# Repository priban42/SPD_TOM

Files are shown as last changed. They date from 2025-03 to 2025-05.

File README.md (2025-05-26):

# Toilet Occupancy Monitor

This project implements a system for monitoring the occupancy of toilet stalls and recording sanitation events within a faculty building.

## Features

- Detects stall occupancy using a combination of Hall sensors (door open/close) and PIR motion sensors.
- Records sanitation events using RFID tags.
- Sends collected data via WiFi to a web server.
- Web server stores data in SQLite and provides visualization of occupancy and sanitation history.
- User-friendly web interface with floor plans and detailed stall status.

## Hardware

- ESP32 microcontroller for control and WiFi communication.
- PN532 RFID reader module.
- Hall sensor (OH137) and PIR sensor (SR602) for presence detection.
- Li-ion battery (18650) with power management modules.

## Software

- Device firmware programmed for sensor reading, event detection, and JSON data transmission.
- Web server implemented in Python using Flask framework.
- Data visualization based on SVG floor plans.

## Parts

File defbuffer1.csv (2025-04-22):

Style | Standard
Append Mode | 1
Fill Mode | 1
Capacity | 100000
Count | 21027
Base Time Seconds | 1744929068
Base Time Fractional | .628364260
Index | Reading | Unit | Range Digits | Disp Digits | Math | Start Group | Limit1 High | Limit1 Low | Limit2 High | Limit2 Low | Terminal | Questionable | Origin | Value | Unit | Digits | Output | Sense | Source Limit | Overtemp | Date | Time | Fractional Seconds
1 | 1.899451490317e-05 | Amp DC | 1 | 6.5 | F | F | F | F | F | F | Front | F | Main | 0.0001027817780 | Volt DC | 1 | F | 2W | F | F | 04/17/2025 | 22:31:08 | .628364260
2 | 7.437442036462e-06 | Amp DC | 1 | 6.5 | F | F | F | F | F | F | Front | F | Main | -0.0001242152648 | Volt DC | 1 | F | 2W | F | F | 04/17/2025 | 22:31:08 | .631889340
3 | 1.899451490317e-05 | Amp DC | 1 | 6.5 | F | F | F | F | F | F | Front | F | Main | 0.0001027817780 | Volt DC | 1 | F | 2W | F | F | 04/17/2025 | 22:31:08 | .635377580
4 | 1.899413655337e-05 | Amp DC | 1 | 6.5 | F | F | F | F | F | F | Front | F | Main | -0.0000107176747 | Volt DC | 1 | F | 2W | F | F | 04/17/2025 | 22:31:08 | .638861860
5 | 1.899451490317e-05 | Amp DC | 1 | 6.5 | F | F | F | F | F | F | Front | F | Main | -0.0000107185988 | Volt DC | 1 | F | 2W | F | F | 04/17/2025 | 22:31:08 | .642365300
6 | 1.899413655337e-05 | Amp DC | 1 | 6.5 | F | F | F | F | F | F | Front | F | Main | 0.0001027817780 | Volt DC | 1 | F | 2W | F | F | 04/17/2025 | 22:31:08 | .645855260
7 | 1.899451490317e-05 | Amp DC | 1 | 6.5 | F | F | F | F | F | F | Front | F | Main | 0.0001027817780 | Volt DC | 1 | F | 2W | F | F | 04/17/2025 | 22:31:08 | .649350460
8 | 1.899451490317e-05 | Amp DC | 1 | 6.5 | F | F | F | F | F | F | Front | F | Main | -0.0000107185988 | Volt DC | 1 | F | 2W | F | F | 04/17/2025 | 22:31:08 | .652854140
9 | 7.43772216083e-06 | Amp DC | 1 | 6.5 | F | F | F | F | F | F | Front | F | Main | 0.0001027817780 | Volt DC | 1 | F | 2W | F | F | 04/17/2025 | 22:31:08 | .656342200
10 | 1.899413655337e-05 | Amp DC | 1 | 6.5 | F | F | F | F | F | F | Front | F | Main | -0.0000107176747 | Volt DC | 1 | F | 2W | F | F | 04/17/2025 | 22:31:08 | .659834880
11 | 3.055101115024e-05 | Amp DC | 1 | 6.5 | F | F | F | F | F | F | Front | F | Main | -0.0000107185988 | Volt DC | 1 | F | 2W | F | F | 04/17/2025 | 22:31:08 | .663328260
12 | 3.055101115024e-05 | Amp DC | 1 | 6.5 | F | F | F | F | F | F | Front | F | Main | 0.0001027817780 | Volt DC | 1 | F | 2W | F | F | 04/17/2025 | 22:31:08 | .666814880
13 | 1.899451490317e-05 | Amp DC | 1 | 6.5 | F | F | F | F | F | F | Front | F | Main | -0.0000107185988 | Volt DC | 1 | F | 2W | F | F | 04/17/2025 | 22:31:08 | .670305920
14 | 1.899451490317e-05 | Amp DC | 1 | 6.5 | F | F | F | F | F | F | Front | F | Main | -0.0000107185988 | Volt DC | 1 | F | 2W | F | F | 04/17/2025 | 22:31:08 | .673803360
15 | 1.899413655337e-05 | Amp DC | 1 | 6.5 | F | F | F | F | F | F | Front | F | Main | -0.0000107176747 | Volt DC | 1 | F | 2W | F | F | 04/17/2025 | 22:31:08 | .677299720
16 | 1.899488597701e-05 | Amp DC | 1 | 6.5 | F | F | F | F | F | F | Front | F | Main | -0.0000107195156 | Volt DC | 1 | F | 2W | F | F | 04/17/2025 | 22:31:08 | .680796760
17 | 1.899413655337e-05 | Amp DC | 1 | 6.5 | F | F | F | F | F | F | Front | F | Main | 0.0001027817780 | Volt DC | 1 | F | 2W | F | F | 04/17/2025 | 22:31:08 | .684284560
18 | 1.899451490317e-05 | Amp DC | 1 | 6.5 | F | F | F | F | F | F | Front | F | Main | -0.0001242189755 | Volt DC | 1 | F | 2W | F | F | 04/17/2025 | 22:31:08 | .687781080
19 | 1.899451490317e-05 | Amp DC | 1 | 6.5 | F | F | F | F | F | F | Front | F | Main | -0.0000107185988 | Volt DC | 1 | F | 2W | F | F | 04/17/2025 | 22:31:08 | .691278700
20 | 1.899451490317e-05 | Amp DC | 1 | 6.5 | F | F | F | F | F | F | Front | F | Main | -0.0000107185988 | Volt DC | 1 | F | 2W | F | F | 04/17/2025 | 22:31:08 | .694774800
21 | 1.899413655337e-05 | Amp DC | 1 | 6.5 | F | F | F | F | F | F | Front | F | Main | -0.0000107176747 | Volt DC | 1 | F | 2W | F | F | 04/17/2025 | 22:31:08 | .698256940
22 | 7.438005923177e-06 | Amp DC | 1 | 6.5 | F | F | F | F | F | F | Front | F | Main | 0.0001027817780 | Volt DC | 1 | F | 2W | F | F | 04/17/2025 | 22:31:08 | .701757300
23 | 3.055148408748e-05 | Amp DC | 1 | 6.5 | F | F | F | F | F | F | Front | F | Main | 0.0001027817780 | Volt DC | 1 | F | 2W | F | F | 04/17/2025 | 22:31:08 | .705240080
24 | -4.118686774746e-06 | Amp DC | 1 | 6.5 | F | F | F | F | F | F | Front | F | Main | -0.0001242171274 | Volt DC | 1 | F | 2W | F | F | 04/17/2025 | 22:31:08 | .708733920
25 | 1.899451490317e-05 | Amp DC | 1 | 6.5 | F | F | F | F | F | F | Front | F | Main | 0.0001027817780 | Volt DC | 1 | F | 2W | F | F | 04/17/2025 | 22:31:08 | .712229020
26 | 3.055148408748e-05 | Amp DC | 1 | 6.5 | F | F | F | F | F | F | Front | F | Main | 0.0001027817780 | Volt DC | 1 | F | 2W | F | F | 04/17/2025 | 22:31:08 | .715723320
27 | 1.899413655337e-05 | Amp DC | 1 | 6.5 | F | F | F | F | F | F | Front | F | Main | -0.0000107176747 | Volt DC | 1 | F | 2W | F | F | 04/17/2025 | 22:31:08 | .719209900
28 | 7.437442036462e-06 | Amp DC | 1 | 6.5 | F | F | F | F | F | F | Front | F | Main | -0.0001242152648 | Volt DC | 1 | F | 2W | F | F | 04/17/2025 | 22:31:08 | .722717500
29 | 1.899451490317e-05 | Amp DC | 1 | 6.5 | F | F | F | F | F | F | Front | F | Main | -0.0001242189755 | Volt DC | 1 | F | 2W | F | F | 04/17/2025 | 22:31:08 | .726208460
30 | 1.899488597701e-05 | Amp DC | 1 | 6.5 | F | F | F | F | F | F | Front | F | Main | -0.0000107195156 | Volt DC | 1 | F | 2W | F | F | 04/17/2025 | 22:31:08 | .729710020
31 | 1.899451490317e-05 | Amp DC | 1 | 6.5 | F | F | F | F | F | F | Front | F | Main | 0.0001027817780 | Volt DC | 1 | F | 2W | F | F | 04/17/2025 | 22:31:08 | .733204280
32 | 1.899451490317e-05 | Amp DC | 1 | 6.5 | F | F | F | F | F | F | Front | F | Main | 0.0001027817780 | Volt DC | 1 | F | 2W | F | F | 04/17/2025 | 22:31:08 | .736700640
33 | 4.210752376821e-05 | Amp DC | 1 | 6.5 | F | F | F | F | F | F | Front | F | Main | 0.0001027817780 | Volt DC | 1 | F | 2W | F | F | 04/17/2025 | 22:31:08 | .740196240
34 | 7.43772216083e-06 | Amp DC | 1 | 6.5 | F | F | F | F | F | F | Front | F | Main | -0.0001242171274 | Volt DC | 1 | F | 2W | F | F | 04/17/2025 | 22:31:08 | .743700200
35 | 7.43772216083e-06 | Amp DC | 1 | 6.5 | F | F | F | F | F | F | Front | F | Main | -0.0000107176747 | Volt DC | 1 | F | 2W | F | F | 04/17/2025 | 22:31:08 | .747187960
36 | 1.899413655337e-05 | Amp DC | 1 | 6.5 | F | F | F | F | F | F | Front | F | Main | -0.0000107176747 | Volt DC | 1 | F | 2W | F | F | 04/17/2025 | 22:31:08 | .750697300
37 | 1.899451490317e-05 | Amp DC | 1 | 6.5 | F | F | F | F | F | F | Front | F | Main | -0.0000107185988 | Volt DC | 1 | F | 2W | F | F | 04/17/2025 | 22:31:08 | .754184920
38 | 1.899413655337e-05 | Amp DC | 1 | 6.5 | F | F | F | F | F | F | Front | F | Main | -0.0000107176747 | Volt DC | 1 | F | 2W | F | F | 04/17/2025 | 22:31:08 | .757678960
39 | 1.899413655337e-05 | Amp DC | 1 | 6.5 | F | F | F | F | F | F | Front | F | Main | 0.0001027817780 | Volt DC | 1 | F | 2W | F | F | 04/17/2025 | 22:31:08 | .761170800
40 | 3.055148408748e-05 | Amp DC | 1 | 6.5 | F | F | F | F | F | F | Front | F | Main | 0.0001027817780 | Volt DC | 1 | F | 2W | F | F | 04/17/2025 | 22:31:08 | .764665780
41 | 1.899413655337e-05 | Amp DC | 1 | 6.5 | F | F | F | F | F | F | Front | F | Main | 0.0001027817780 | Volt DC | 1 | F | 2W | F | F | 04/17/2025 | 22:31:08 | .768152760
42 | 7.43772216083e-06 | Amp DC | 1 | 6.5 | F | F | F | F | F | F | Front | F | Main | -0.0002377165656 | Volt DC | 1 | F | 2W | F | F | 04/17/2025 | 22:31:08 | .771647500
43 | 1.899451490317e-05 | Amp DC | 1 | 6.5 | F | F | F | F | F | F | Front | F | Main | -0.0000107185988 | Volt DC | 1 | F | 2W | F | F | 04/17/2025 | 22:31:08 | .775144360
44 | 1.899413655337e-05 | Amp DC | 1 | 6.5 | F | F | F | F | F | F | Front | F | Main | -0.0000107176747 | Volt DC | 1 | F | 2W | F | F | 04/17/2025 | 22:31:08 | .778635900
45 | 3.055148408748e-05 | Amp DC | 1 | 6.5 | F | F | F | F | F | F | Front | F | Main | -0.0000107195156 | Volt DC | 1 | F | 2W | F | F | 04/17/2025 | 22:31:08 | .782137940
46 | 1.899451490317e-05 | Amp DC | 1 | 6.5 | F | F | F | F | F | F | Front | F | Main | -0.0000107185988 | Volt DC | 1 | F | 2W | F | F | 04/17/2025 | 22:31:08 | .785626280
47 | 7.438005923177e-06 | Amp DC | 1 | 6.5 | F | F | F | F | F | F | Front | F | Main | -0.0000107185988 | Volt DC | 1 | F | 2W | F | F | 04/17/2025 | 22:31:08 | .789108080
48 | 1.899413655337e-05 | Amp DC | 1 | 6.5 | F | F | F | F | F | F | Front | F | Main | 0.0001027817780 | Volt DC | 1 | F | 2W | F | F | 04/17/2025 | 22:31:08 | .792606520
49 | -4.118686774746e-06 | Amp DC | 1 | 6.5 | F | F | F | F | F | F | Front | F | Main | -0.0001242171274 | Volt DC | 1 | F | 2W | F | F | 04/17/2025 | 22:31:08 | .796088800
50 | 7.43772216083e-06 | Amp DC | 1 | 6.5 | F | F | F | F | F | F | Front | F | Main | -0.0001242171274 | Volt DC | 1 | F | 2W | F | F | 04/17/2025 | 22:31:08 | .799568960
51 | 1.899413655337e-05 | Amp DC | 1 | 6.5 | F | F | F | F | F | F | Front | F | Main | -0.0000107176747 | Volt DC | 1 | F | 2W | F | F | 04/17/2025 | 22:31:08 | .803068880
52 | 7.438005923177e-06 | Amp DC | 1 | 6.5 | F | F | F | F | F | F | Front | F | Main | 0.0001027817780 | Volt DC | 1 | F | 2W | F | F | 04/17/2025 | 22:31:08 | .806552980
53 | 1.899451490317e-05 | Amp DC | 1 | 6.5 | F | F | F | F | F | F | Front | F | Main | -0.0000107185988 | Volt DC | 1 | F | 2W | F | F | 04/17/2025 | 22:31:08 | .810052540
54 | 1.899413655337e-05 | Amp DC | 1 | 6.5 | F | F | F | F | F | F | Front | F | Main | -0.0001242171274 | Volt DC | 1 | F | 2W | F | F | 04/17/2025 | 22:31:08 | .813544060
55 | 7.437442036462e-06 | Amp DC | 1 | 6.5 | F | F | F | F | F | F | Front | F | Main | -0.0000107167434 | Volt DC | 1 | F | 2W | F | F | 04/17/2025 | 22:31:08 | .817030040
56 | 1.899451490317e-05 | Amp DC | 1 | 6.5 | F | F | F | F | F | F | Front | F | Main | -0.0000107185988 | Volt DC | 1 | F | 2W | F | F | 04/17/2025 | 22:31:08 | .820521600
57 | -4.118686774746e-06 | Amp DC | 1 | 6.5 | F | F | F | F | F | F | Front | F | Main | -0.0001242171274 | Volt DC | 1 | F | 2W | F | F | 04/17/2025 | 22:31:08 | .824012100
58 | 1.899451490317e-05 | Amp DC | 1 | 6.5 | F | F | F | F | F | F | Front | F | Main | -0.0000107185988 | Volt DC | 1 | F | 2W | F | F | 04/17/2025 | 22:31:08 | .827494740
59 | 3.055054548895e-05 | Amp DC | 1 | 6.5 | F | F | F | F | F | F | Front | F | Main | 0.0001027817780 | Volt DC | 1 | F | 2W | F | F | 04/17/2025 | 22:31:08 | .830990060
60 | 7.43772216083e-06 | Amp DC | 1 | 6.5 | F | F | F | F | F | F | Front | F | Main | -0.0000107176747 | Volt DC | 1 | F | 2W | F | F | 04/17/2025 | 22:31:08 | .834472160
61 | 7.438005923177e-06 | Amp DC | 1 | 6.5 | F | F | F | F | F | F | Front | F | Main | -0.0000107185988 | Volt DC | 1 | F | 2W | F | F | 04/17/2025 | 22:31:08 | .837957860
62 | 7.438005923177e-06 | Amp DC | 1 | 6.5 | F | F | F | F | F | F | Front | F | Main | -0.0000107185988 | Volt DC | 1 | F | 2W | F | F | 04/17/2025 | 22:31:08 | .841454880
63 | 1.899451490317e-05 | Amp DC | 1 | 6.5 | F | F | F | F | F | F | Front | F | Main | -0.0000107185988 | Volt DC | 1 | F | 2W | F | F | 04/17/2025 | 22:31:08 | .844939920
64 | 3.055054548895e-05 | Amp DC | 1 | 6.5 | F | F | F | F | F | F | Front | F | Main | 0.0001027817780 | Volt DC | 1 | F | 2W | F | F | 04/17/2025 | 22:31:08 | .848427260
65 | 3.055148408748e-05 | Amp DC | 1 | 6.5 | F | F | F | F | F | F | Front | F | Main | 0.0001027817780 | Volt DC | 1 | F | 2W | F | F | 04/17/2025 | 22:31:08 | .851927080
66 | -4.118875949644e-06 | Amp DC | 1 | 6.5 | F | F | F | F | F | F | Front | F | Main | -0.0000107167434 | Volt DC | 1 | F | 2W | F | F | 04/17/2025 | 22:31:08 | .855410580
67 | 7.437442036462e-06 | Amp DC | 1 | 6.5 | F | F | F | F | F | F | Front | F | Main | -0.0000107167434 | Volt DC | 1 | F | 2W | F | F | 04/17/2025 | 22:31:08 | .858895800
68 | 1.899413655337e-05 | Amp DC | 1 | 6.5 | F | F | F | F | F | F | Front | F | Main | -0.0000107176747 | Volt DC | 1 | F | 2W | F | F | 04/17/2025 | 22:31:08 | .862388300
69 | 7.438005923177e-06 | Amp DC | 1 | 6.5 | F | F | F | F | F | F | Front | F | Main | 0.0001027817780 | Volt DC | 1 | F | 2W | F | F | 04/17/2025 | 22:31:08 | .865876520
70 | 3.055148408748e-05 | Amp DC | 1 | 6.5 | F | F | F | F | F | F | Front | F | Main | 0.0001027817780 | Volt DC | 1 | F | 2W | F | F | 04/17/2025 | 22:31:08 | .869357180
71 | 3.055148408748e-05 | Amp DC | 1 | 6.5 | F | F | F | F | F | F | Front | F | Main | 0.0001027817780 | Volt DC | 1 | F | 2W | F | F | 04/17/2025 | 22:31:08 | .872854620
72 | 3.055148408748e-05 | Amp DC | 1 | 6.5 | F | F | F | F | F | F | Front | F | Main | -0.0000107195156 | Volt DC | 1 | F | 2W | F | F | 04/17/2025 | 22:31:08 | .876340400
73 | 1.899451490317e-05 | Amp DC | 1 | 6.5 | F | F | F | F | F | F | Front | F | Main | -0.0000107185988 | Volt DC | 1 | F | 2W | F | F | 04/17/2025 | 22:31:08 | .879821200
74 | 1.899451490317e-05 | Amp DC | 1 | 6.5 | F | F | F | F | F | F | Front | F | Main | 0.0001027817780 | Volt DC | 1 | F | 2W | F | F | 04/17/2025 | 22:31:08 | .883312820
75 | 1.899451490317e-05 | Amp DC | 1 | 6.5 | F | F | F | F | F | F | Front | F | Main | -0.0001242189755 | Volt DC | 1 | F | 2W | F | F | 04/17/2025 | 22:31:08 | .886805340
76 | 1.899413655337e-05 | Amp DC | 1 | 6.5 | F | F | F | F | F | F | Front | F | Main | -0.0000107176747 | Volt DC | 1 | F | 2W | F | F | 04/17/2025 | 22:31:08 | .890308120
77 | 3.055148408748e-05 | Amp DC | 1 | 6.5 | F | F | F | F | F | F | Front | F | Main | 0.0001027817780 | Volt DC | 1 | F | 2W | F | F | 04/17/2025 | 22:31:08 | .893807720
78 | 7.438005923177e-06 | Amp DC | 1 | 6.5 | F | F | F | F | F | F | Front | F | Main | -0.0000107185988 | Volt DC | 1 | F | 2W | F | F | 04/17/2025 | 22:31:08 | .897288800
79 | 1.899451490317e-05 | Amp DC | 1 | 6.5 | F | F | F | F | F | F | Front | F | Main | -0.0001242189755 | Volt DC | 1 | F | 2W | F | F | 04/17/2025 | 22:31:08 | .900787480
80 | 1.899413655337e-05 | Amp DC | 1 | 6.5 | F | F | F | F | F | F | Front | F | Main | -0.0000107176747 | Volt DC | 1 | F | 2W | F | F | 04/17/2025 | 22:31:08 | .904274160
81 | 3.055148408748e-05 | Amp DC | 1 | 6.5 | F | F | F | F | F | F | Front | F | Main | -0.0000107195156 | Volt DC | 1 | F | 2W | F | F | 04/17/2025 | 22:31:08 | .907771860
82 | 1.899413655337e-05 | Amp DC | 1 | 6.5 | F | F | F | F | F | F | Front | F | Main | -0.0000107176747 | Volt DC | 1 | F | 2W | F | F | 04/17/2025 | 22:31:08 | .911266000
83 | 3.055148408748e-05 | Amp DC | 1 | 6.5 | F | F | F | F | F | F | Front | F | Main | 0.0001027817780 | Volt DC | 1 | F | 2W | F | F | 04/17/2025 | 22:31:08 | .914755960
84 | 1.899413655337e-05 | Amp DC | 1 | 6.5 | F | F | F | F | F | F | Front | F | Main | -0.0001242171274 | Volt DC | 1 | F | 2W | F | F | 04/17/2025 | 22:31:08 | .918236720
85 | 1.899413655337e-05 | Amp DC | 1 | 6.5 | F | F | F | F | F | F | Front | F | Main | -0.0000107176747 | Volt DC | 1 | F | 2W | F | F | 04/17/2025 | 22:31:08 | .921736860
86 | 7.438005923177e-06 | Amp DC | 1 | 6.5 | F | F | F | F | F | F | Front | F | Main | -0.0000107185988 | Volt DC | 1 | F | 2W | F | F | 04/17/2025 | 22:31:08 | .925220400
87 | 1.899451490317e-05 | Amp DC | 1 | 6.5 | F | F | F | F | F | F | Front | F | Main | -0.0000107185988 | Volt DC | 1 | F | 2W | F | F | 04/17/2025 | 22:31:08 | .928716080
88 | 3.055101115024e-05 | Amp DC | 1 | 6.5 | F | F | F | F | F | F | Front | F | Main | 0.0001027817780 | Volt DC | 1 | F | 2W | F | F | 04/17/2025 | 22:31:08 | .932222320
89 | 1.899451490317e-05 | Amp DC | 1 | 6.5 | F | F | F | F | F | F | Front | F | Main | -0.0000107185988 | Volt DC | 1 | F | 2W | F | F | 04/17/2025 | 22:31:08 | .935718900
90 | 3.055101115024e-05 | Amp DC | 1 | 6.5 | F | F | F | F | F | F | Front | F | Main | 0.0001027817780 | Volt DC | 1 | F | 2W | F | F | 04/17/2025 | 22:31:08 | .939203220
91 | 7.438005923177e-06 | Amp DC | 1 | 6.5 | F | F | F | F | F | F | Front | F | Main | -0.0000107185988 | Volt DC | 1 | F | 2W | F | F | 04/17/2025 | 22:31:08 | .942714820
92 | 7.43772216083e-06 | Amp DC | 1 | 6.5 | F | F | F | F | F | F | Front | F | Main | -0.0000107176747 | Volt DC | 1 | F | 2W | F | F | 04/17/2025 | 22:31:08 | .946199000
93 | 1.899451490317e-05 | Amp DC | 1 | 6.5 | F | F | F | F | F | F | Front | F | Main | -0.0000107185988 | Volt DC | 1 | F | 2W | F | F | 04/17/2025 | 22:31:08 | .949700220
94 | 7.437442036462e-06 | Amp DC | 1 | 6.5 | F | F | F | F | F | F | Front | F | Main | -0.0001242152648 | Volt DC | 1 | F | 2W | F | F | 04/17/2025 | 22:31:08 | .953199160
95 | 1.899413655337e-05 | Amp DC | 1 | 6.5 | F | F | F | F | F | F | Front | F | Main | -0.0000107176747 | Volt DC | 1 | F | 2W | F | F | 04/17/2025 | 22:31:08 | .956693460
96 | 3.055148408748e-05 | Amp DC | 1 | 6.5 | F | F | F | F | F | F | Front | F | Main | 0.0001027817780 | Volt DC | 1 | F | 2W | F | F | 04/17/2025 | 22:31:08 | .960189220
97 | 7.43772216083e-06 | Amp DC | 1 | 6.5 | F | F | F | F | F | F | Front | F | Main | -0.0001242171274 | Volt DC | 1 | F | 2W | F | F | 04/17/2025 | 22:31:08 | .963691920
98 | 3.055101115024e-05 | Amp DC | 1 | 6.5 | F | F | F | F | F | F | Front | F | Main | 0.0001027817780 | Volt DC | 1 | F | 2W | F | F | 04/17/2025 | 22:31:08 | .967175260
99 | 1.899413655337e-05 | Amp DC | 1 | 6.5 | F | F | F | F | F | F | Front | F | Main | -0.0000107176747 | Volt DC | 1 | F | 2W | F | F | 04/17/2025 | 22:31:08 | .970681300
100 | 1.899451490317e-05 | Amp DC | 1 | 6.5 | F | F | F | F | F | F | Front | F | Main | -0.0000107185988 | Volt DC | 1 | F | 2W | F | F | 04/17/2025 | 22:31:08 | .974171060
101 | 1.899451490317e-05 | Amp DC | 1 | 6.5 | F | F | F | F | F | F | Front | F | Main | -0.0000107185988 | Volt DC | 1 | F | 2W | F | F | 04/17/2025 | 22:31:08 | .977652120
102 | 1.899451490317e-05 | Amp DC | 1 | 6.5 | F | F | F | F | F | F | Front | F | Main | -0.0000107185988 | Volt DC | 1 | F | 2W | F | F | 04/17/2025 | 22:31:08 | .981148680
103 | 1.899451490317e-05 | Amp DC | 1 | 6.5 | F | F | F | F | F | F | Front | F | Main | -0.0000107185988 | Volt DC | 1 | F | 2W | F | F | 04/17/2025 | 22:31:08 | .984631300
104 | 4.210808401695e-05 | Amp DC | 1 | 6.5 | F | F | F | F | F | F | Front | F | Main | 0.0001027817780 | Volt DC | 1 | F | 2W | F | F | 04/17/2025 | 22:31:08 | .988112420
105 | 3.055148408748e-05 | Amp DC | 1 | 6.5 | F | F | F | F | F | F | Front | F | Main | 0.0001027817780 | Volt DC | 1 | F | 2W | F | F | 04/17/2025 | 22:31:08 | .991609840
106 | 3.055148408748e-05 | Amp DC | 1 | 6.5 | F | F | F | F | F | F | Front | F | Main | 0.0001027817780 | Volt DC | 1 | F | 2W | F | F | 04/17/2025 | 22:31:08 | .995092440
107 | 1.899413655337e-05 | Amp DC | 1 | 6.5 | F | F | F | F | F | F | Front | F | Main | -0.0000107176747 | Volt DC | 1 | F | 2W | F | F | 04/17/2025 | 22:31:08 | .998574180
108 | 1.899451490317e-05 | Amp DC | 1 | 6.5 | F | F | F | F | F | F | Front | F | Main | -0.0000107185988 | Volt DC | 1 | F | 2W | F | F | 04/17/2025 | 22:31:09 | .002066860
109 | 1.899451490317e-05 | Amp DC | 1 | 6.5 | F | F | F | F | F | F | Front | F | Main | -0.0000107185988 | Volt DC | 1 | F | 2W | F | F | 04/17/2025 | 22:31:09 | .005548520
110 | 1.899451490317e-05 | Amp DC | 1 | 6.5 | F | F | F | F | F | F | Front | F | Main | -0.0000107185988 | Volt DC | 1 | F | 2W | F | F | 04/17/2025 | 22:31:09 | .009035060
111 | 1.899451490317e-05 | Amp DC | 1 | 6.5 | F | F | F | F | F | F | Front | F | Main | -0.0000107185988 | Volt DC | 1 | F | 2W | F | F | 04/17/2025 | 22:31:09 | .012526860
112 | 1.899451490317e-05 | Amp DC | 1 | 6.5 | F | F | F | F | F | F | Front | F | Main | -0.0000107185988 | Volt DC | 1 | F | 2W | F | F | 04/17/2025 | 22:31:09 | .016011800
113 | 1.899451490317e-05 | Amp DC | 1 | 6.5 | F | F | F | F | F | F | Front | F | Main | -0.0000107185988 | Volt DC | 1 | F | 2W | F | F | 04/17/2025 | 22:31:09 | .019497280
114 | 7.43772216083e-06 | Amp DC | 1 | 6.5 | F | F | F | F | F | F | Front | F | Main | -0.0000107176747 | Volt DC | 1 | F | 2W | F | F | 04/17/2025 | 22:31:09 | .022989840
115 | 1.899413655337e-05 | Amp DC | 1 | 6.5 | F | F | F | F | F | F | Front | F | Main | 0.0001027817780 | Volt DC | 1 | F | 2W | F | F | 04/17/2025 | 22:31:09 | .026534820
116 | 7.437442036462e-06 | Amp DC | 1 | 6.5 | F | F | F | F | F | F | Front | F | Main | -0.0001242152648 | Volt DC | 1 | F | 2W | F | F | 04/17/2025 | 22:31:09 | .030054120
117 | 1.899413655337e-05 | Amp DC | 1 | 6.5 | F | F | F | F | F | F | Front | F | Main | -0.0000107176747 | Volt DC | 1 | F | 2W | F | F | 04/17/2025 | 22:31:09 | .033545000
118 | 7.43772216083e-06 | Amp DC | 1 | 6.5 | F | F | F | F | F | F | Front | F | Main | 0.0001027817780 | Volt DC | 1 | F | 2W | F | F | 04/17/2025 | 22:31:09 | .037033960
119 | 1.899413655337e-05 | Amp DC | 1 | 6.5 | F | F | F | F | F | F | Front | F | Main | -0.0000107176747 | Volt DC | 1 | F | 2W | F | F | 04/17/2025 | 22:31:09 | .040530060
120 | 1.899413655337e-05 | Amp DC | 1 | 6.5 | F | F | F | F | F | F | Front | F | Main | -0.0000107176747 | Volt DC | 1 | F | 2W | F | F | 04/17/2025 | 22:31:09 | .044015020
121 | 7.438005923177e-06 | Amp DC | 1 | 6.5 | F | F | F | F | F | F | Front | F | Main | -0.0000107185988 | Volt DC | 1 | F | 2W | F | F | 04/17/2025 | 22:31:09 | .047497380
122 | 3.055148408748e-05 | Amp DC | 1 | 6.5 | F | F | F | F | F | F | Front | F | Main | 0.0001027817780 | Volt DC | 1 | F | 2W | F | F | 04/17/2025 | 22:31:09 | .051001820
123 | 1.899413655337e-05 | Amp DC | 1 | 6.5 | F | F | F | F | F | F | Front | F | Main | -0.0000107176747 | Volt DC | 1 | F | 2W | F | F | 04/17/2025 | 22:31:09 | .054491780
124 | 7.43772216083e-06 | Amp DC | 1 | 6.5 | F | F | F | F | F | F | Front | F | Main | -0.0000107176747 | Volt DC | 1 | F | 2W | F | F | 04/17/2025 | 22:31:09 | .057981040
125 | 1.899413655337e-05 | Amp DC | 1 | 6.5 | F | F | F | F | F | F | Front | F | Main | -0.0000107176747 | Volt DC | 1 | F | 2W | F | F | 04/17/2025 | 22:31:09 | .061472680
126 | 3.055101115024e-05 | Amp DC | 1 | 6.5 | F | F | F | F | F | F | Front | F | Main | 0.0001027817780 | Volt DC | 1 | F | 2W | F | F | 04/17/2025 | 22:31:09 | .064957340
127 | 1.899413655337e-05 | Amp DC | 1 | 6.5 | F | F | F | F | F | F | Front | F | Main | 0.0001027817780 | Volt DC | 1 | F | 2W | F | F | 04/17/2025 | 22:31:09 | .068442140
128 | 3.055101115024e-05 | Amp DC | 1 | 6.5 | F | F | F | F | F | F | Front | F | Main | 0.0001027817780 | Volt DC | 1 | F | 2W | F | F | 04/17/2025 | 22:31:09 | .071934760
129 | 7.43772216083e-06 | Amp DC | 1 | 6.5 | F | F | F | F | F | F | Front | F | Main | -0.0001242171274 | Volt DC | 1 | F | 2W | F | F | 04/17/2025 | 22:31:09 | .075420380
130 | 1.899488597701e-05 | Amp DC | 1 | 6.5 | F | F | F | F | F | F | Front | F | Main | 0.0001027817780 | Volt DC | 1 | F | 2W | F | F | 04/17/2025 | 22:31:09 | .078907900
131 | 3.055101115024e-05 | Amp DC | 1 | 6.5 | F | F | F | F | F | F | Front | F | Main | 0.0002162799647 | Volt DC | 1 | F | 2W | F | F | 04/17/2025 | 22:31:09 | .082399980
132 | 1.899451490317e-05 | Amp DC | 1 | 6.5 | F | F | F | F | F | F | Front | F | Main | -0.0000107185988 | Volt DC | 1 | F | 2W | F | F | 04/17/2025 | 22:31:09 | .085886540
133 | 7.43772216083e-06 | Amp DC | 1 | 6.5 | F | F | F | F | F | F | Front | F | Main | 0.0001027817780 | Volt DC | 1 | F | 2W | F | F | 04/17/2025 | 22:31:09 | .089373220
134 | 3.055148408748e-05 | Amp DC | 1 | 6.5 | F | F | F | F | F | F | Front | F | Main | 0.0001027817780 | Volt DC | 1 | F | 2W | F | F | 04/17/2025 | 22:31:09 | .092870180
135 | 7.43772216083e-06 | Amp DC | 1 | 6.5 | F | F | F | F | F | F | Front | F | Main | 0.0001027817780 | Volt DC | 1 | F | 2W | F | F | 04/17/2025 | 22:31:09 | .096356640
136 | 7.43772216083e-06 | Amp DC | 1 | 6.5 | F | F | F | F | F | F | Front | F | Main | -0.0000107176747 | Volt DC | 1 | F | 2W | F | F | 04/17/2025 | 22:31:09 | .099837580
137 | 7.43772216083e-06 | Amp DC | 1 | 6.5 | F | F | F | F | F | F | Front | F | Main | -0.0000107176747 | Volt DC | 1 | F | 2W | F | F | 04/17/2025 | 22:31:09 | .103332660
138 | 7.43772216083e-06 | Amp DC | 1 | 6.5 | F | F | F | F | F | F | Front | F | Main | 0.0001027817780 | Volt DC | 1 | F | 2W | F | F | 04/17/2025 | 22:31:09 | .106843620
139 | 1.899451490317e-05 | Amp DC | 1 | 6.5 | F | F | F | F | F | F | Front | F | Main | -0.0000107185988 | Volt DC | 1 | F | 2W | F | F | 04/17/2025 | 22:31:09 | .110351100
140 | 1.899413655337e-05 | Amp DC | 1 | 6.5 | F | F | F | F | F | F | Front | F | Main | -0.0000107176747 | Volt DC | 1 | F | 2W | F | F | 04/17/2025 | 22:31:09 | .113846200
141 | 1.899413655337e-05 | Amp DC | 1 | 6.5 | F | F | F | F | F | F | Front | F | Main | 0.0001027817780 | Volt DC | 1 | F | 2W | F | F | 04/17/2025 | 22:31:09 | .117327320
142 | 1.899451490317e-05 | Amp DC | 1 | 6.5 | F | F | F | F | F | F | Front | F | Main | 0.0001027817780 | Volt DC | 1 | F | 2W | F | F | 04/17/2025 | 22:31:09 | .120822440
143 | 3.055101115024e-05 | Amp DC | 1 | 6.5 | F | F | F | F | F | F | Front | F | Main | -0.0000107185988 | Volt DC | 1 | F | 2W | F | F | 04/17/2025 | 22:31:09 | .124318780
144 | 1.899451490317e-05 | Amp DC | 1 | 6.5 | F | F | F | F | F | F | Front | F | Main | -0.0000107185988 | Volt DC | 1 | F | 2W | F | F | 04/17/2025 | 22:31:09 | .127800620
145 | 1.899413655337e-05 | Amp DC | 1 | 6.5 | F | F | F | F | F | F | Front | F | Main | -0.0000107176747 | Volt DC | 1 | F | 2W | F | F | 04/17/2025 | 22:31:09 | .131296820
146 | 1.899413655337e-05 | Amp DC | 1 | 6.5 | F | F | F | F | F | F | Front | F | Main | -0.0000107176747 | Volt DC | 1 | F | 2W | F | F | 04/17/2025 | 22:31:09 | .134789820
147 | 7.43772216083e-06 | Amp DC | 1 | 6.5 | F | F | F | F | F | F | Front | F | Main | -0.0000107176747 | Volt DC | 1 | F | 2W | F | F | 04/17/2025 | 22:31:09 | .138268200
148 | 7.438005923177e-06 | Amp DC | 1 | 6.5 | F | F | F | F | F | F | Front | F | Main | 0.0001027817780 | Volt DC | 1 | F | 2W | F | F | 04/17/2025 | 22:31:09 | .141777720
149 | 1.899451490317e-05 | Amp DC | 1 | 6.5 | F | F | F | F | F | F | Front | F | Main | -0.0000107185988 | Volt DC | 1 | F | 2W | F | F | 04/17/2025 | 22:31:09 | .145264180
150 | 3.055148408748e-05 | Amp DC | 1 | 6.5 | F | F | F | F | F | F | Front | F | Main | 0.0001027817780 | Volt DC | 1 | F | 2W | F | F | 04/17/2025 | 22:31:09 | .148768460
151 | 3.055148408748e-05 | Amp DC | 1 | 6.5 | F | F | F | F | F | F | Front | F | Main | 0.0001027817780 | Volt DC | 1 | F | 2W | F | F | 04/17/2025 | 22:31:09 | .152270240
152 | 1.899451490317e-05 | Amp DC | 1 | 6.5 | F | F | F | F | F | F | Front | F | Main | 0.0001027817780 | Volt DC | 1 | F | 2W | F | F | 04/17/2025 | 22:31:09 | .155761400
153 | 3.055101115024e-05 | Amp DC | 1 | 6.5 | F | F | F | F | F | F | Front | F | Main | 0.0001027817780 | Volt DC | 1 | F | 2W | F | F | 04/17/2025 | 22:31:09 | .159250560
154 | 1.899488597701e-05 | Amp DC | 1 | 6.5 | F | F | F | F | F | F | Front | F | Main | 0.0001027817780 | Volt DC | 1 | F | 2W | F | F | 04/17/2025 | 22:31:09 | .162754940
155 | 1.899413655337e-05 | Amp DC | 1 | 6.5 | F | F | F | F | F | F | Front | F | Main | -0.0000107176747 | Volt DC | 1 | F | 2W | F | F | 04/17/2025 | 22:31:09 | .166237300
156 | 1.899451490317e-05 | Amp DC | 1 | 6.5 | F | F | F | F | F | F | Front | F | Main | 0.0001027817780 | Volt DC | 1 | F | 2W | F | F | 04/17/2025 | 22:31:09 | .169725500
157 | 1.899413655337e-05 | Amp DC | 1 | 6.5 | F | F | F | F | F | F | Front | F | Main | -0.0000107176747 | Volt DC | 1 | F | 2W | F | F | 04/17/2025 | 22:31:09 | .173217240
158 | 1.899413655337e-05 | Amp DC | 1 | 6.5 | F | F | F | F | F | F | Front | F | Main | -0.0000107176747 | Volt DC | 1 | F | 2W | F | F | 04/17/2025 | 22:31:09 | .176712160
159 | 1.899451490317e-05 | Amp DC | 1 | 6.5 | F | F | F | F | F | F | Front | F | Main | -0.0000107185988 | Volt DC | 1 | F | 2W | F | F | 04/17/2025 | 22:31:09 | .180200880
160 | 7.438005923177e-06 | Amp DC | 1 | 6.5 | F | F | F | F | F | F | Front | F | Main | -0.0000107185988 | Volt DC | 1 | F | 2W | F | F | 04/17/2025 | 22:31:09 | .183703680
161 | 7.438005923177e-06 | Amp DC | 1 | 6.5 | F | F | F | F | F | F | Front | F | Main | -0.0000107185988 | Volt DC | 1 | F | 2W | F | F | 04/17/2025 | 22:31:09 | .187189840
162 | 1.899451490317e-05 | Amp DC | 1 | 6.5 | F | F | F | F | F | F | Front | F | Main | -0.0000107185988 | Volt DC | 1 | F | 2W | F | F | 04/17/2025 | 22:31:09 | .190698300
163 | 7.438005923177e-06 | Amp DC | 1 | 6.5 | F | F | F | F | F | F | Front | F | Main | 0.0001027817780 | Volt DC | 1 | F | 2W | F | F | 04/17/2025 | 22:31:09 | .194189100
164 | 1.899451490317e-05 | Amp DC | 1 | 6.5 | F | F | F | F | F | F | Front | F | Main | -0.0000107185988 | Volt DC | 1 | F | 2W | F | F | 04/17/2025 | 22:31:09 | .197678560
165 | 1.899451490317e-05 | Amp DC | 1 | 6.5 | F | F | F | F | F | F | Front | F | Main | -0.0000107185988 | Volt DC | 1 | F | 2W | F | F | 04/17/2025 | 22:31:09 | .201168400
166 | 1.899413655337e-05 | Amp DC | 1 | 6.5 | F | F | F | F | F | F | Front | F | Main | 0.0001027817780 | Volt DC | 1 | F | 2W | F | F | 04/17/2025 | 22:31:09 | .204651240
167 | 1.899451490317e-05 | Amp DC | 1 | 6.5 | F | F | F | F | F | F | Front | F | Main | -0.0000107185988 | Volt DC | 1 | F | 2W | F | F | 04/17/2025 | 22:31:09 | .208136220
168 | 1.899451490317e-05 | Amp DC | 1 | 6.5 | F | F | F | F | F | F | Front | F | Main | -0.0000107185988 | Volt DC | 1 | F | 2W | F | F | 04/17/2025 | 22:31:09 | .211638040
169 | 1.899488597701e-05 | Amp DC | 1 | 6.5 | F | F | F | F | F | F | Front | F | Main | 0.0001027817780 | Volt DC | 1 | F | 2W | F | F | 04/17/2025 | 22:31:09 | .215120500
170 | 7.438005923177e-06 | Amp DC | 1 | 6.5 | F | F | F | F | F | F | Front | F | Main | -0.0000107185988 | Volt DC | 1 | F | 2W | F | F | 04/17/2025 | 22:31:09 | .218615240
171 | 3.055101115024e-05 | Amp DC | 1 | 6.5 | F | F | F | F | F | F | Front | F | Main | 0.0001027817780 | Volt DC | 1 | F | 2W | F | F | 04/17/2025 | 22:31:09 | .222104660
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

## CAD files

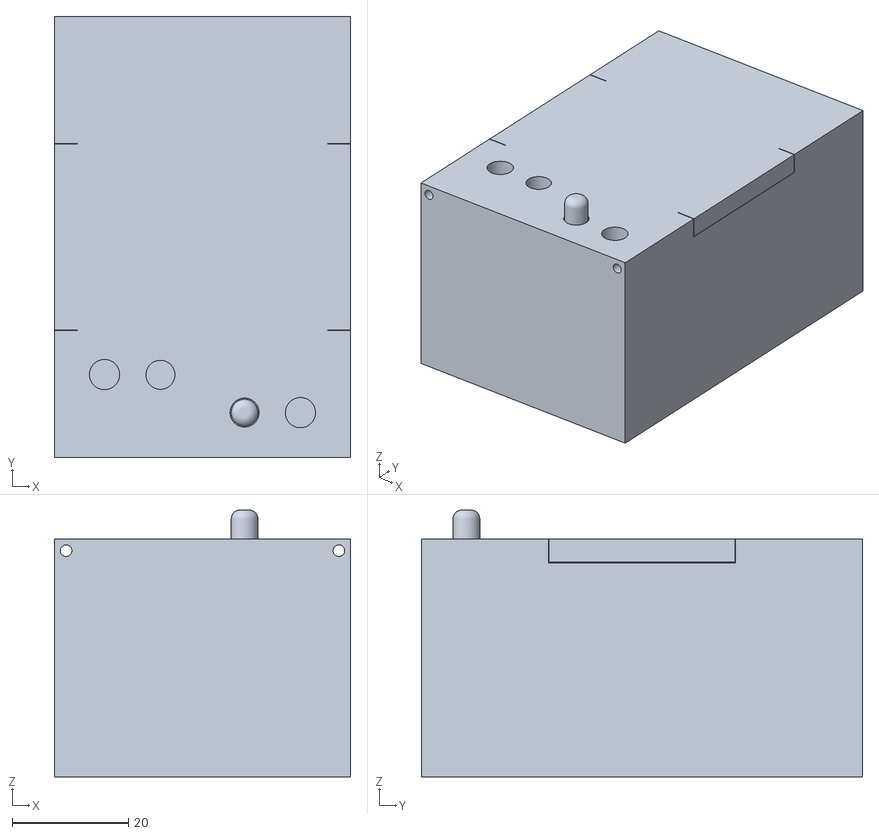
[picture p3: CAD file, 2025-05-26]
client/cases_STL/NFC_case.stl
51.0 x 76.0 x 46.0

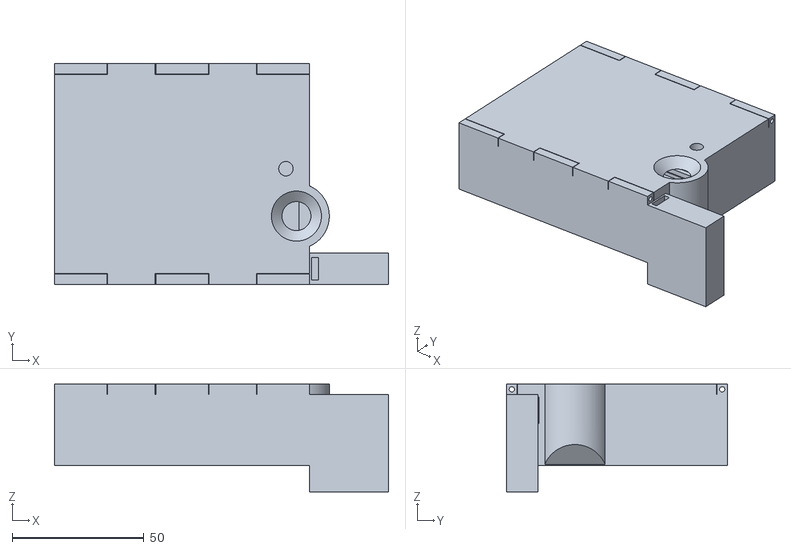
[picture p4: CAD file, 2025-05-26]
client/cases_STL/presence_case.stl
127.0 x 84.0 x 41.0

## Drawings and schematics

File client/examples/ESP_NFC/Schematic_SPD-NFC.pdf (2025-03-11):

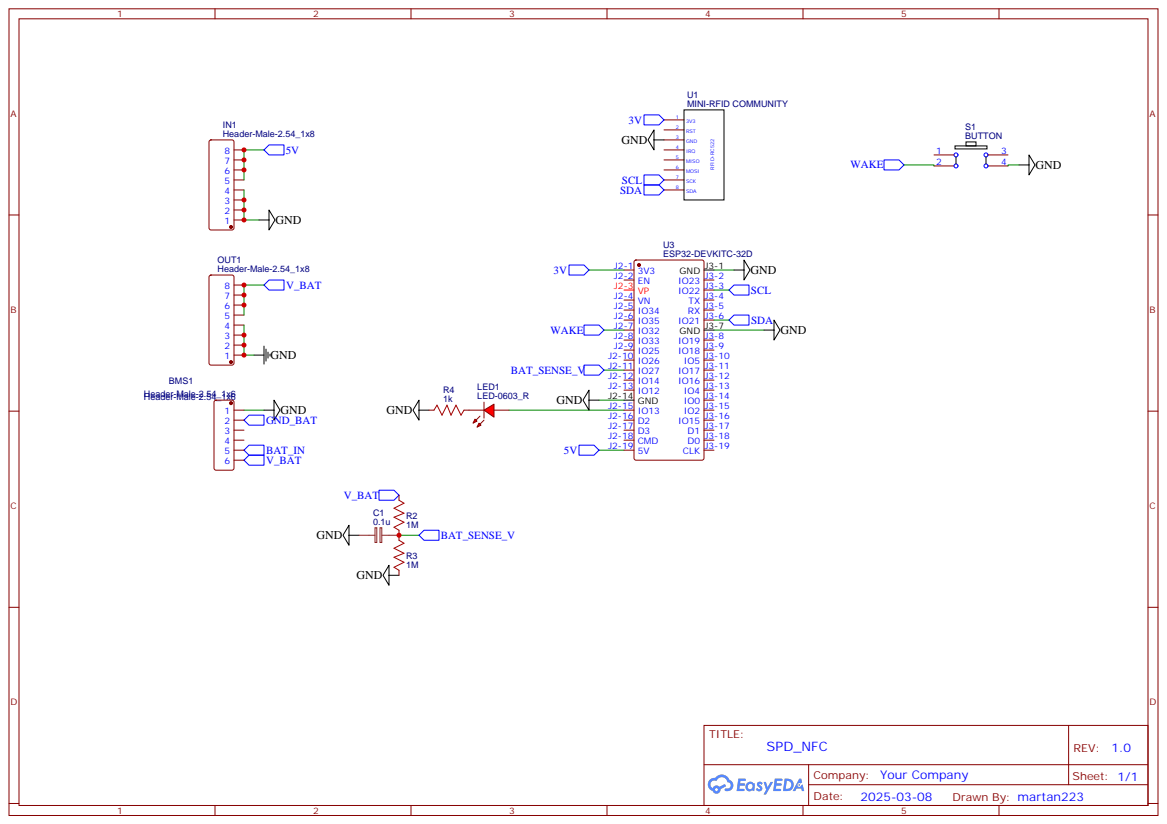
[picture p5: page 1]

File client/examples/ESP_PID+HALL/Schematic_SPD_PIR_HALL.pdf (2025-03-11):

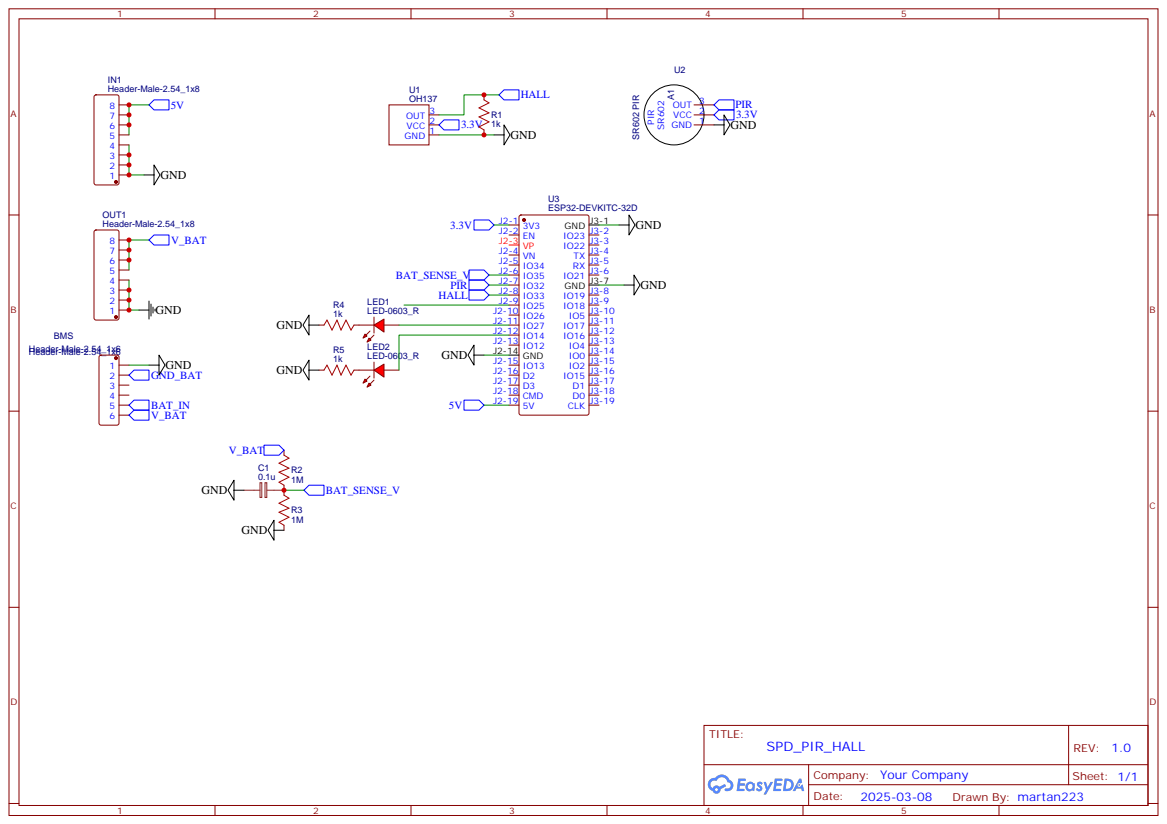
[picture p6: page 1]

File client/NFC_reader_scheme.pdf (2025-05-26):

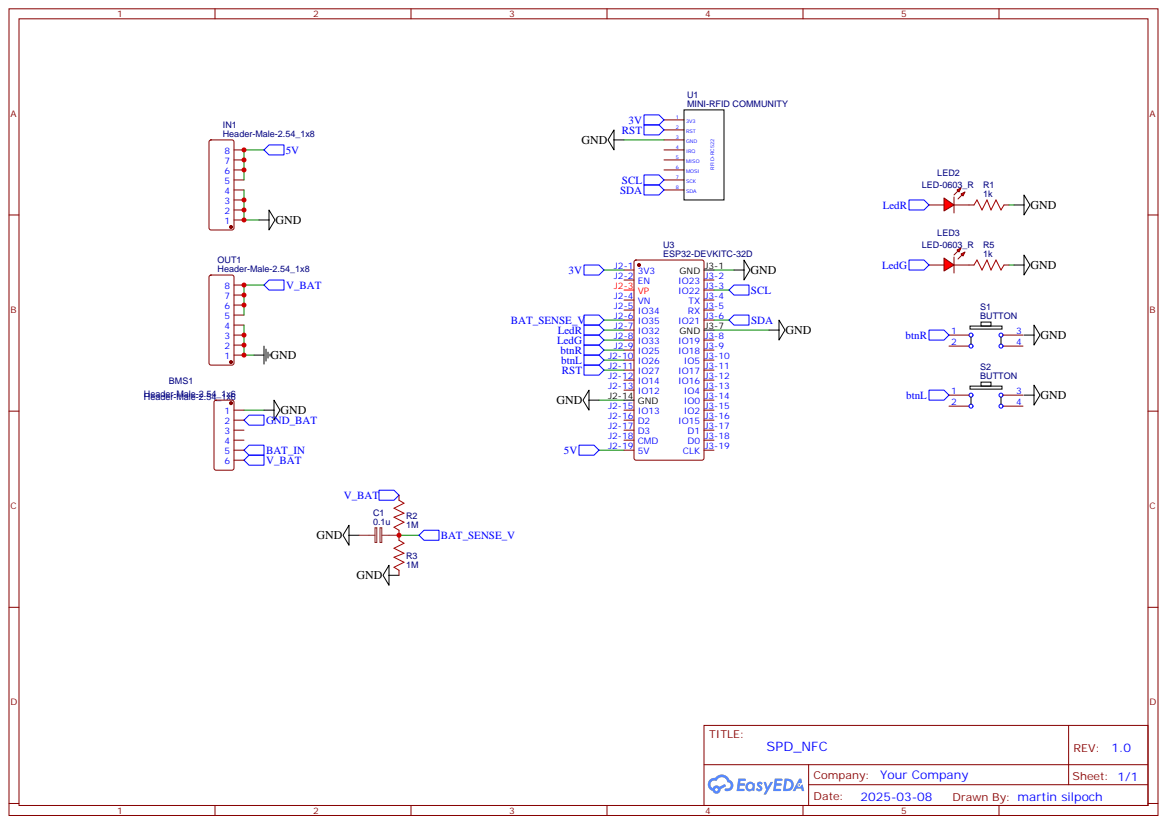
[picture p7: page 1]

Drawn By: martin silpoch

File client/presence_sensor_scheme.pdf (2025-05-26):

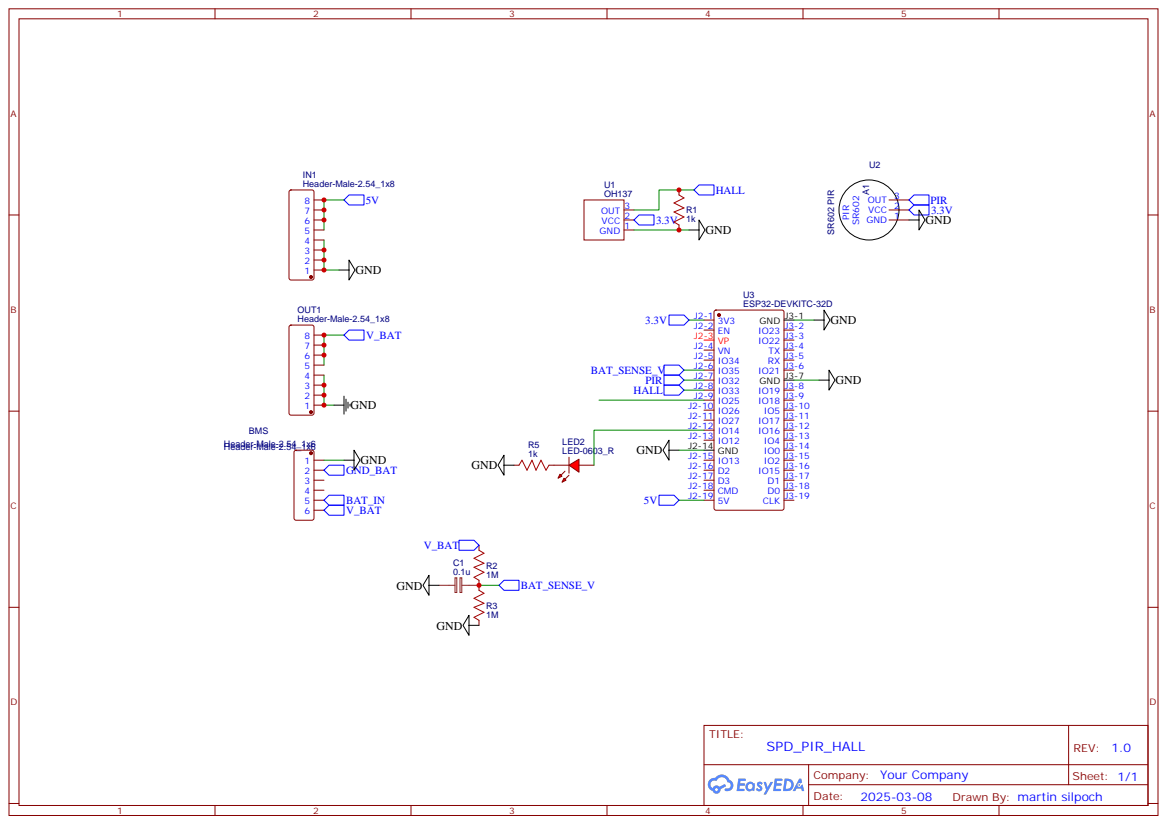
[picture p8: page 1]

Drawn By: martin silpoch

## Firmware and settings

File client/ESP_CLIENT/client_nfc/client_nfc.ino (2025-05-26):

#include <WiFi.h>
#include <HTTPClient.h>
#include <ArduinoJson.h>
#include <time.h>
#include "data_sender.h"
#include "wifi_login.h"
#include "esp_sleep.h"
#include "driver/rtc_io.h"
#include <Wire.h>
#include <PN532_I2C.h>
#include <PN532.h>
#include <NfcAdapter.h>

//NFC setup
//PN532_I2C pn532_i2c(Wire);
//NfcAdapter nfc = NfcAdapter(pn532_i2c);

#define I2C_SDA 21
#define I2C_SCL 22
#define PN532_RESET_PIN  27 
TwoWire I2CBus = TwoWire(0);
PN532_I2C pn532_i2c(I2CBus);
NfcAdapter nfc = NfcAdapter(pn532_i2c);

const int ledR = 32;
const int ledG = 33;
const int btnR = 25;
const int btnG = 26;

bool connectToEduroam = false;

//standard wifi credentials
const char* ssid = "xxx";
const char* wifiPassword = "yyy";

//eduroam wifi credentials
char* EAP_ANONYMOUS_IDENTITY = "anonymous@cvut.cz";
char* EAP_IDENTITY = "xxx@cvut.cz";
char* EAP_PASSWORD = "xxx";
char* EAP_USERNAME = "xxx@cvut.cz";

//ntp setup
const char* ntpServer = "pool.ntp.org";
const long  gmtOffset_sec = 3600;
const int   daylightOffset_sec = 3600;

//node settings
const char* serverUrl = "http://0.1.2.3:5000/data";
const char* node_id = "T2_B2_1_0_F_3";
const int stall_id = -1;
const char* nodePassword = "password"; 

bool DEBUG = true;
String UID = "";

void setup() {
  pinMode(PN532_RESET_PIN, OUTPUT);
  pinMode(ledR, OUTPUT);
  pinMode(ledG, OUTPUT);
  pinMode(btnR, INPUT_PULLUP);
  pinMode(btnG, INPUT_PULLUP);
  digitalWrite(ledR, LOW);
  digitalWrite(ledG, LOW);
  Serial.begin(115200);

  // reset pn532
  digitalWrite(PN532_RESET_PIN, LOW);
  delay(100);
  digitalWrite(PN532_RESET_PIN, HIGH);
  delay(100);
  I2CBus.end(); 
  delay(100);
  I2CBus.begin(I2C_SDA, I2C_SCL, 400000); 
  nfc.begin();

  //connect to wifi
  if (connectToEduroam)
    {
      logInEduroam(EAP_IDENTITY, EAP_USERNAME, EAP_PASSWORD);
    }
  else
  {
    logInWifi(ssid, wifiPassword);
  }


  configTime(gmtOffset_sec, daylightOffset_sec, ntpServer);
}


void loop() {
  if (!digitalRead(btnR)){
    digitalWrite(ledR, HIGH);
    Serial.println("STOP button pressed");
    if(readRFID(0)){
    for(int i = 0; i < 10; i++){
      digitalWrite(ledR, LOW);
      delay(100);
      digitalWrite(ledR, HIGH);
      delay(100);
    }
    digitalWrite(ledR, LOW);
    }
    else{
      error();
    }
  }
  if (!digitalRead(btnG)){
    digitalWrite(ledG,HIGH);
    Serial.println("START button pressed");
    if(readRFID(1)){
    for(int i = 0; i < 10; i++){
      digitalWrite(ledG, LOW);
      delay(100);
      digitalWrite(ledG, HIGH);
      delay(100);
    }
    digitalWrite(ledG, LOW);
    }
    else{
      error();
    }
  }
}


bool readRFID(int action)
{
  if(nfc.tagPresent()){
  NfcTag tag = nfc.read();
  UID = tag.getUidString();
  Serial.print("UID: ");
  Serial.println(UID);
  int length = UID.length();
  char* buffer = new char[length + 1];
  UID.toCharArray(buffer, length + 1);
  sendData(3, buffer,action) ;
  delete[] buffer;
  return true;
  }
  return false;
}

void error()
{
  Serial.println("no card detected");
  for(int i = 0; i < 10; i++){
      digitalWrite(ledG, HIGH);
      delay(100);
      digitalWrite(ledG, LOW);
      digitalWrite(ledR, HIGH);
      delay(100);
      digitalWrite(ledR, LOW);
    }
    digitalWrite(ledR, LOW);
    digitalWrite(ledG, LOW);
}

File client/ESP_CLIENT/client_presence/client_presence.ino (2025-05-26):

#include <WiFi.h>
#include <HTTPClient.h>
#include <ArduinoJson.h>
#include <time.h>
#include "data_sender.h"
#include "wifi_login.h"
#include "esp_sleep.h"
#include "driver/rtc_io.h"

#define WAKEUP_PIN_EXT0     GPIO_NUM_32
#define WAKEUP_LEVEL_EXT0   0          
#define WAKEUP_PIN_EXT1     GPIO_NUM_33
#define WAKEUP_BITMASK_EXT1 (1ULL << WAKEUP_PIN_EXT1)
#define AWAKE_TIME_MS       5000

int LED = 27;
int WakeUpReason = -1;
bool connectToEduroam = false;

//standard wifi credentials
const char* ssid = "xxx";
const char* wifiPassword = "yyy";

//eduroam wifi credentials
char* EAP_ANONYMOUS_IDENTITY = "anonymous@cvut.cz";
char* EAP_IDENTITY = "xxx@cvut.cz";
char* EAP_PASSWORD = "xxx";
char* EAP_USERNAME = "xxx@cvut.cz";

//ntp setup
const char* ntpServer = "pool.ntp.org";
const long  gmtOffset_sec = 3600;
const int   daylightOffset_sec = 3600;

//node settings
const char* serverUrl = "http://0.1.2.3:5000/data";
const char* node_id = "T2_B3_1_0_M_3";
const int stall_id = 1;
const char* nodePassword = "password"; 

bool DEBUG = true;

void setup() {
  pinMode(LED, OUTPUT);
  pinMode(GPIO_NUM_32,INPUT);
  pinMode(GPIO_NUM_33,INPUT);
  digitalWrite(LED, HIGH);
  Serial.begin(115200);
  delay(100);

  esp_sleep_wakeup_cause_t wakeup_reason = esp_sleep_get_wakeup_cause();
  switch(wakeup_reason) {
    case ESP_SLEEP_WAKEUP_EXT0:
      Serial.println("HALL wake up");
      if(digitalRead(WAKEUP_PIN_EXT0))
      {
        WakeUpReason = 0;
      }
      else{
      WakeUpReason = 1;
      }
      break;
    case ESP_SLEEP_WAKEUP_EXT1:
      Serial.println("PIR wake up");
      WakeUpReason = 2;
      while (digitalRead(33) == HIGH) {
      delay(10);
      } 
      break;
    case ESP_SLEEP_WAKEUP_TIMER:
      Serial.println("timer wake up");
      break;
    default:
      Serial.println("other wake up");
      break;
  }
  //connect to wifi
  if (connectToEduroam)
    {
      logInEduroam(EAP_IDENTITY, EAP_USERNAME, EAP_PASSWORD);
    }
  else
  {
    logInWifi(ssid, wifiPassword);
  }


  configTime(gmtOffset_sec, daylightOffset_sec, ntpServer);
}


void loop() {
  if (WakeUpReason != -1)
  {
    sendData(WakeUpReason, "-1") ;
  }
  digitalWrite(LED, LOW);
  Serial.println("going to sleep");
  Serial.flush();

  //setting wakeups
  if (digitalRead(WAKEUP_PIN_EXT0))
  {
    esp_sleep_enable_ext0_wakeup(WAKEUP_PIN_EXT0, 0);
  }
  else
  {
    esp_sleep_enable_ext0_wakeup(WAKEUP_PIN_EXT0, 1);
  }
  rtc_gpio_pulldown_en(WAKEUP_PIN_EXT0);
  rtc_gpio_pullup_dis(WAKEUP_PIN_EXT0);
  esp_sleep_enable_ext1_wakeup_io(WAKEUP_BITMASK_EXT1, ESP_EXT1_WAKEUP_ANY_HIGH);
  rtc_gpio_pullup_dis(WAKEUP_PIN_EXT1);
  rtc_gpio_pulldown_en(WAKEUP_PIN_EXT1);
  while (digitalRead(WAKEUP_PIN_EXT1))
  {
    delay(500);
    Serial.println("waiting for pir to go to 0");
  }
  esp_deep_sleep_start();
}

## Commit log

2025-03-11 esp32 schemes for PID+HALL and RFID esp32 testing codes
2025-04-14 added heatmaps for toilets, stalls
2025-04-17 added buffer measurements (card reader without sleep)
    [defbuffer1.csv]
2025-04-27 added plots for individual stalls. added filter for day/week/month/year
2025-05-26 final version of client side
    [NFC_case.stl, presence_case.stl]
